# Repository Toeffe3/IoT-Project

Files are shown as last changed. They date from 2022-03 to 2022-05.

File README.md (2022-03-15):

# IoT-Project
University Project designing an IoT system

# Setup IDE
### Microchip studio

Following architectures are required:



_Run the `as-installer-*.exe` and select `AVR` and `UC3` (click **Repair**, if you have MCS installed but missing any of the architectures)_

Following extensions are optional:
* `ClangFormat`
* `Git Source Controle Provider`

---

**Integrate with Git trickery**

Open the project the first time by double-clicking the `IoT-Project.atsln` file, if no projects apperes in the Solution Explorer, you have to manually add them by left-clicking the Solution -> Add -> Existing Project -> Navigate to either one of the `*.ccproj` files, and repeat for the other.

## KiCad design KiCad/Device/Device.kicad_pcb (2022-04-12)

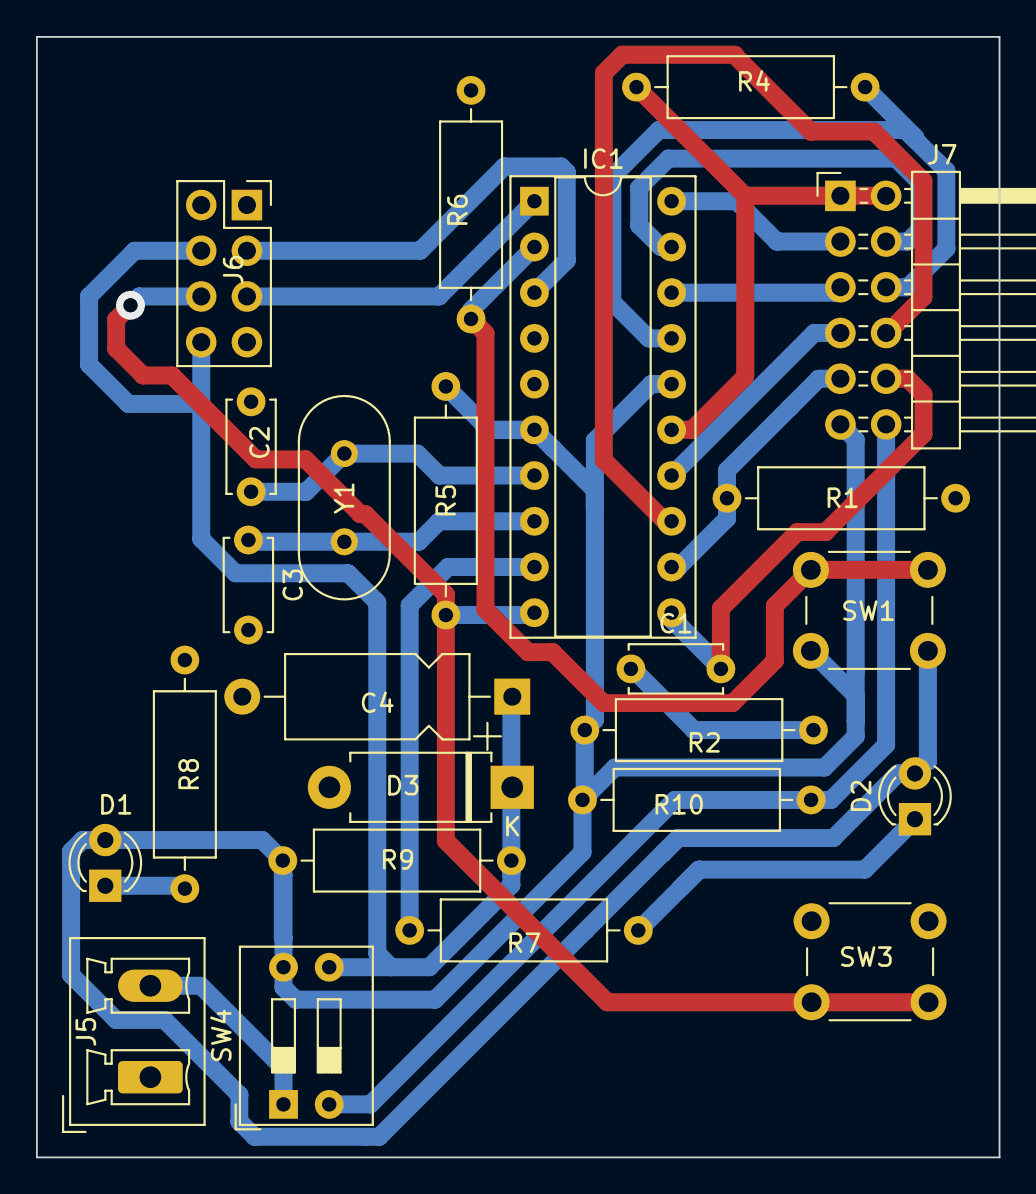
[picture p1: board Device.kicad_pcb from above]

Board: 2 copper layers, 53.5 x 62.2 mm, 24 parts (0 on the bottom side), 23 nets.

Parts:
C1: 1uF; C_Disc_D5.0mm_W2.5mm_P5.00mm
C2, C3: 20pF; C_Disc_D5.0mm_W2.5mm_P5.00mm
C4: 200n; CP_Axial_L10.0mm_D4.5mm_P15.00mm_Horizontal
D1: RødLED; LED_D3.0mm_FlatTop
D2: GrønLED; LED_D3.0mm_FlatTop
D3: BZX79C3V3; D_DO-15_P10.16mm_Horizontal
IC1: ATTINY167-XUR; DIP-20_W7.62mm_Socket
J5: VCC; PhoenixContact_MCV_1,5_2-G-5.08_1x02_P5.08mm_Vertical
J6: ESP8266(wifi); PinSocket_2x04_P2.54mm_Vertical
J7: Conn_02x06_Counter_Clockwise; PinHeader_2x06_P2.54mm_Horizontal
R1: 10k; R_Axial_DIN0309_L9.0mm_D3.2mm_P12.70mm_Horizontal
R2: 2.2k; R_Axial_DIN0309_L9.0mm_D3.2mm_P12.70mm_Horizontal
R4: 100k; R_Axial_DIN0309_L9.0mm_D3.2mm_P12.70mm_Horizontal
R5, R6: 1k; R_Axial_DIN0309_L9.0mm_D3.2mm_P12.70mm_Horizontal
R7, R8: 200; R_Axial_DIN0309_L9.0mm_D3.2mm_P12.70mm_Horizontal
R9, R10: 15; R_Axial_DIN0309_L9.0mm_D3.2mm_P12.70mm_Horizontal
SW1, SW3: SW_MEC_5E; SW_PUSH_6mm_H4.3mm
SW4: SW_DIP_x02; SW_DIP_SPSTx02_Slide_9.78x7.26mm_W7.62mm_P2.54mm
Y1: Crystal; Crystal_HC18-U_Vertical

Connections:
+3V3: C4.1, D3.1 (K), J6.4, J6.8, R9.1, SW4.3
+5V: D1.2 (A), D2.2 (A), IC1.6 (VCC), IC1.16 (AVCC), J7.11, R2.2, R5.2, R9.2, R10.1, SW1.1, SW4.4
Button01: IC1.2 (PB1/DO/OC1BU/PCINT9), R6.1, SW1.2 (A)
DHT11: IC1.20 (PA0/RXLIN/RXD/ADC0/PCINT0), J7.3
GND: C2.2, C3.2, C4.2, D3.2 (A), IC1.5 (GND), IC1.15 (AGND), J5.1, J6.1, J7.1, J7.2, R1.2, R4.2, R6.2, R8.2, SW3.1
LED_G: IC1.9 (PB6/INT0/OC1AX/ADC9/PCINT14), R7.2
MIC: C1.1, R2.1
unnamed: D1.1 (K), R8.1
unnamed: D2.1 (K), R7.1
unnamed: J5.2, SW4.1
OPTISK: IC1.17 (PA3/INT1/ISRC/ADC3/PCINT3), J7.6, R4.1
PHOTRAN: IC1.12 (PA6/~SS/AIN0/ADC6/PCINT6), J7.9, R1.1
Reset: IC1.10 (PB7/DW/~RESET/OC1BX/ADC10/PCINT15), J6.6, R5.1, SW3.2 (A)
SCL: IC1.3 (PB2/SCL/USCK/OC1AV/PCINT10), J6.3
SDA: IC1.1 (PB0/SDA/DI/OCR1AU/PCINT8), J6.5
UP1: IC1.19 (PA1/TXLIN/TXD/ADC1/PCINT1), J7.4
UP2: IC1.18 (PA2/MISO/DO/OC0A/ADC2/PCINT2), J7.5
UP4: IC1.14 (PA4/MOSI/SDA/DI/ICP1/ADC4/PCINT4), J7.7
UP5: IC1.13 (PA5/SCK/SCL/USCK/T1/ADC5/PCINT5), J7.8
UP7: C1.2, IC1.11 (PA7/AREF/XREF/AIN1ADC7/PCINT7), J7.10
UPWR: J7.12, R10.2, SW4.2
XTAL1: C2.1, IC1.7 (PB4/CLKI/XTAL1/OC1AW/PCINT12), Y1.1
XTAL2: C3.1, IC1.8 (PB5/CLKO/XTAL2/OC1BW/ADC8/PCINT13), Y1.2

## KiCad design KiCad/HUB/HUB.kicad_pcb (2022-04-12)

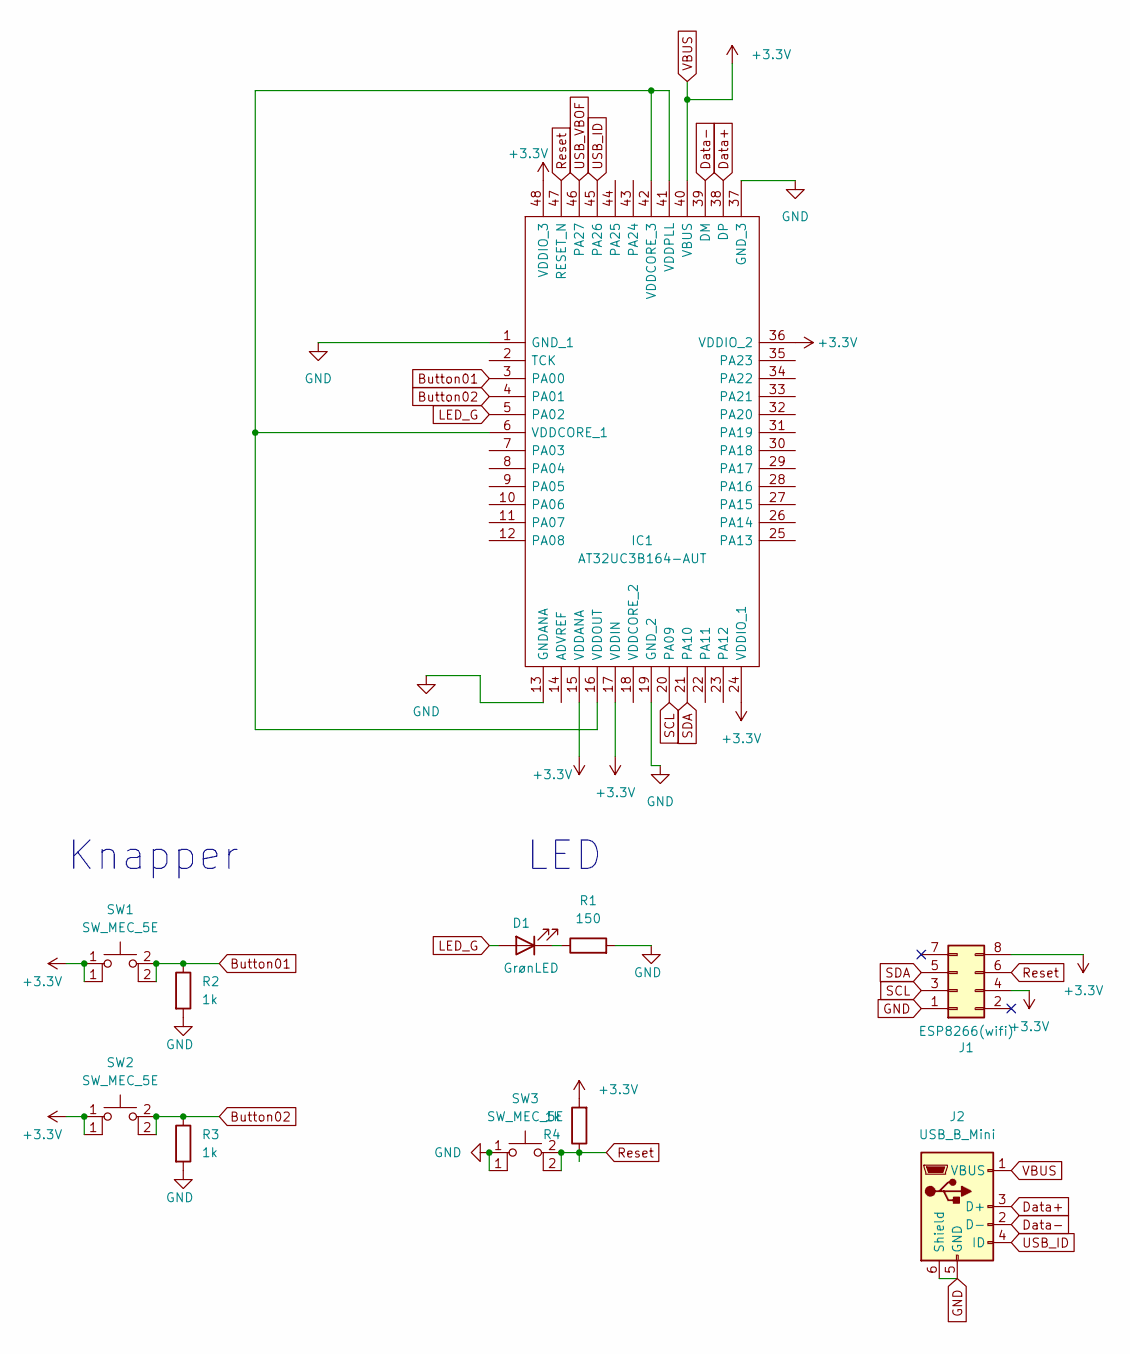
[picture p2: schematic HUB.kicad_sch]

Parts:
D1: GrønLED; LED_D3.0mm_FlatTop
IC1: AT32UC3B164-AUT; QFP50P900X900X120-48N; Mouser Part Number 556-AT32UC3B164-AUT
J1: ESP8266(wifi); PinSocket_2x04_P2.54mm_Vertical
J2: USB_B_Mini; USB_Mini-B_Lumberg_2486_01_Horizontal
R1: 150; R_Axial_DIN0309_L9.0mm_D3.2mm_P12.70mm_Horizontal
R2, R3, R4: 1k; R_Axial_DIN0309_L9.0mm_D3.2mm_P12.70mm_Horizontal
SW1, SW2, SW3: SW_MEC_5E; SW_PUSH_6mm_H4.3mm

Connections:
Button01: IC1.3 (PA00), R2.1, SW1.2 (A)
Button02: IC1.4 (PA01), R3.1, SW2.2 (A)
Data+: IC1.38 (DP), J2.3 (D+)
Data-: IC1.39 (DM), J2.2 (D-)
GND: IC1.1 (GND_1), IC1.13 (GNDANA), IC1.19 (GND_2), IC1.37 (GND_3), J1.1, J2.5 (GND), J2.6 (Shield), R1.2, R2.2, R3.2, SW3.1
LED_G: D1.2 (A), IC1.5 (PA02)
unnamed: D1.1 (K), R1.1
unnamed: IC1.6 (VDDCORE_1), IC1.16 (VDDOUT), IC1.41 (VDDPLL), IC1.42 (VDDCORE_3)
Reset: IC1.47 (RESET_N), J1.6, R4.1, SW3.2 (A)
SCL: IC1.20 (PA09), J1.3
SDA: IC1.21 (PA10), J1.5
USB_ID: IC1.45 (PA26), J2.4 (ID)
USB_VBOF: IC1.46 (PA27)
VBUS: IC1.15 (VDDANA), IC1.17 (VDDIN), IC1.24 (VDDIO_1), IC1.36 (VDDIO_2), IC1.40 (VBUS), IC1.48 (VDDIO_3), J1.4, J1.8, J2.1 (VBUS), R4.2, SW1.1, SW2.1

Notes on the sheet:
LED
Knapper

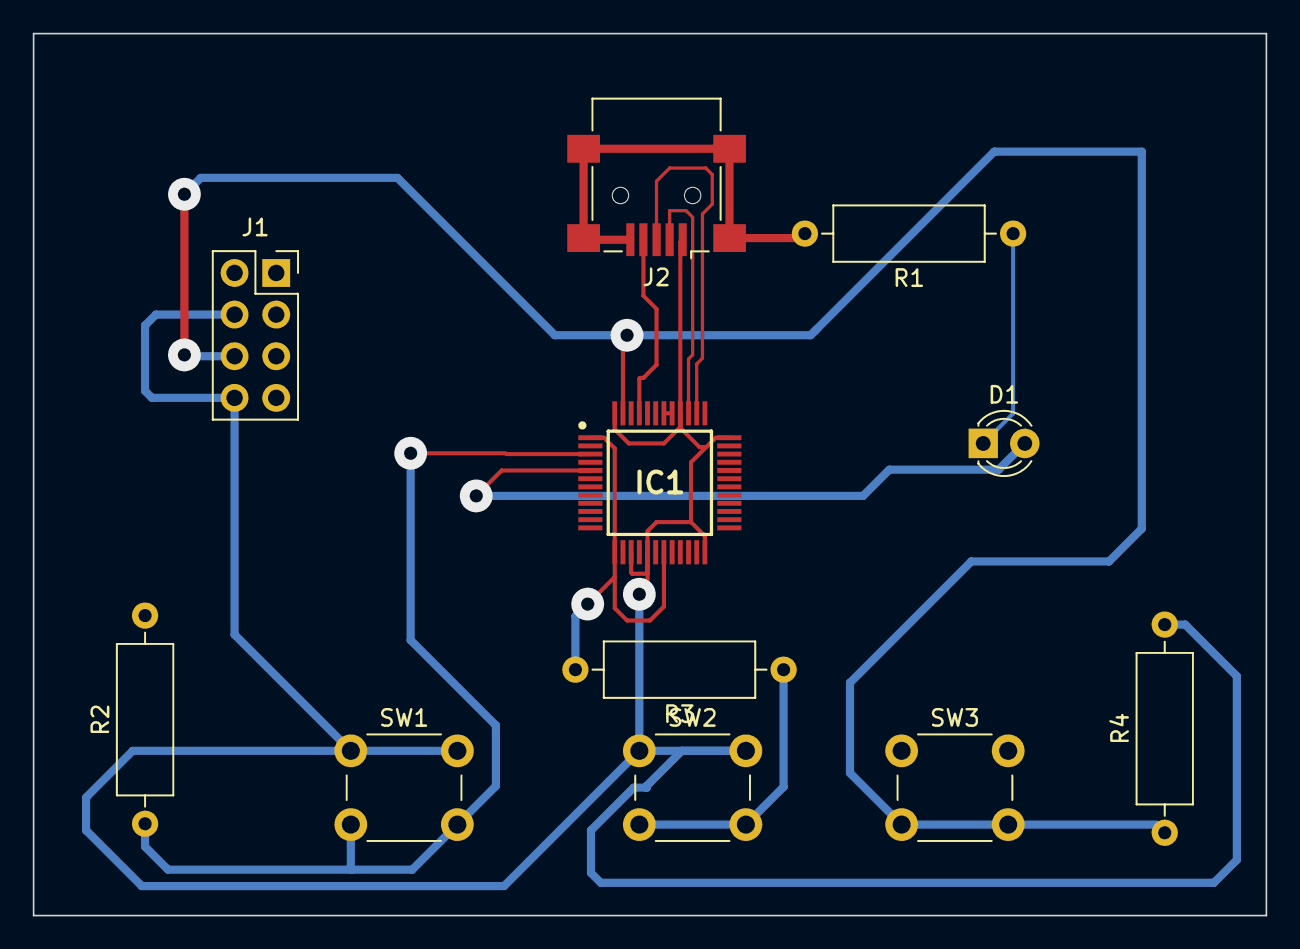
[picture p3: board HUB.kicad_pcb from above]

Board: 2 copper layers, 75.2 x 53.8 mm, 11 parts (0 on the bottom side), 13 nets.

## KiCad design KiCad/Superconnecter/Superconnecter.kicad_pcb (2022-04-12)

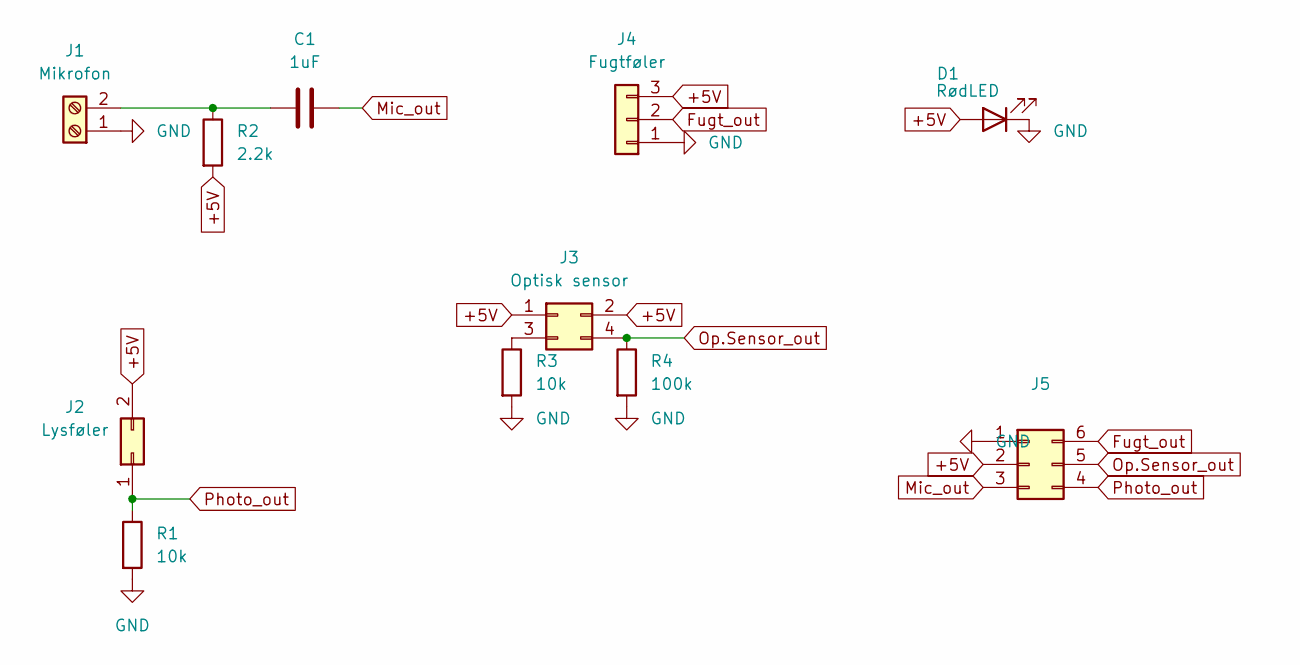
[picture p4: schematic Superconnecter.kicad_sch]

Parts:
C1: 1uF; C_Disc_D5.0mm_W2.5mm_P5.00mm
D1: RødLED; LED_D3.0mm_FlatTop
J1: Mikrofon; PhoenixContact_MCV_1,5_2-G-5.08_1x02_P5.08mm_Vertical
J2: Lysføler; PinSocket_2x01_P2.54mm_Vertical
J3: Optisk sensor; PinSocket_2x02_P2.54mm_Vertical
J4: Fugtføler; PinSocket_1x03_P2.54mm_Vertical
J5: (no value)
R1, R3: 10k; R_Axial_DIN0309_L9.0mm_D3.2mm_P12.70mm_Horizontal
R2: 2.2k; R_Axial_DIN0309_L9.0mm_D3.2mm_P12.70mm_Horizontal
R4: 100k; R_Axial_DIN0309_L9.0mm_D3.2mm_P12.70mm_Horizontal

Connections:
+5V: D1.2 (A), J2.2, J3.1, J3.2, J4.3, J5.2, R2.2
Fugt_out: J4.2, J5.6
GND: D1.1 (K), J1.1, J4.1, J5.1, R1.2, R3.2, R4.2
Mic_out: C1.2, J5.3
unnamed: C1.1, J1.2, R2.1
unnamed: J3.3, R3.1
Op.Sensor_out: J3.4, J5.5, R4.1
Photo_out: J2.1, J5.4, R1.1

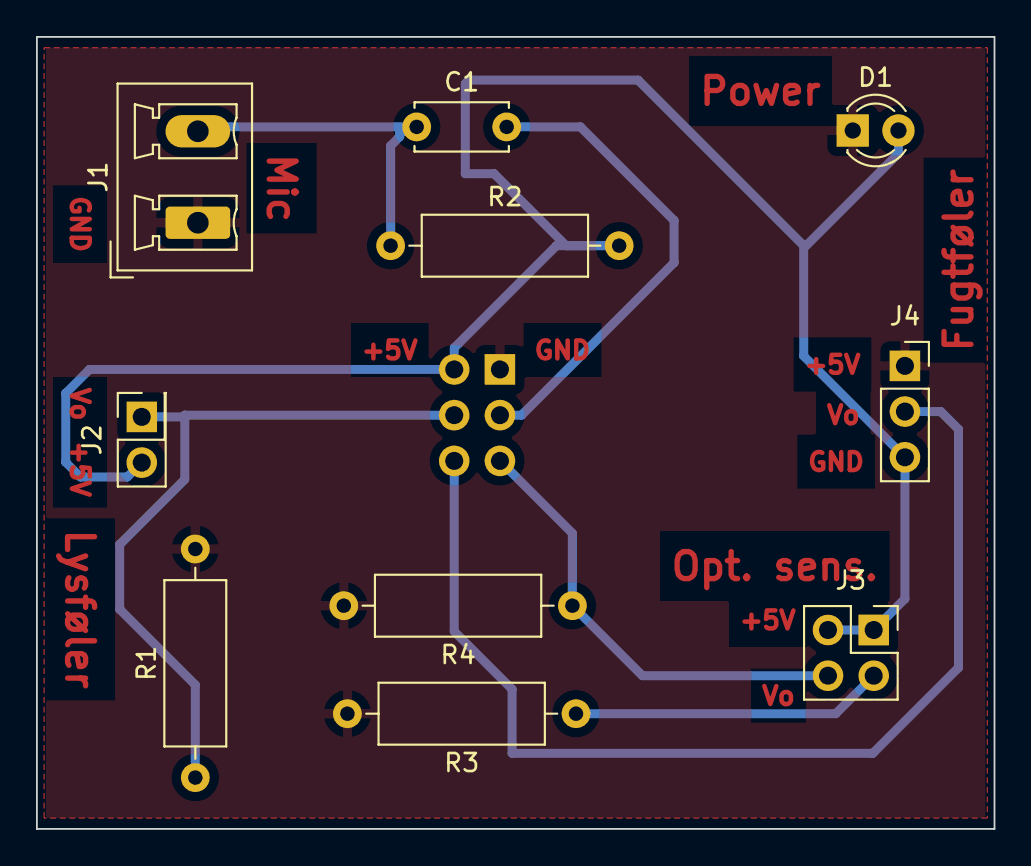
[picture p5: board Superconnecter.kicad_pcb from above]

Board: 2 copper layers, 53.2 x 44.0 mm, 11 parts (1 on the bottom side), 8 nets.

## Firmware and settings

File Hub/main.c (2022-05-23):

/******************************************************************************/
/* Project:    Hub                                                            */
/* File:       main.c                                                         */
/* Decription: Hub main file                                                  */
/******************************************************************************/

/***************************** Include files *******************************/
#include <stdint.h>
//
#include "FreeRTOS.h"
#include "tm4c123gh6pm.h"
//
#include "stream_buffer.h"
#include "systick_frt.h"
#include "task.h"
//
#include "com.h"
#include "lcd.h"
#include "status_led.h"
#include "uart0.h"

/*****************************    Defines    *******************************/
#define USERTASK_STACK_SIZE configMINIMAL_STACK_SIZE

/*****************************   Variables   *******************************/
//@formatter:off
char sensor_text[5][16] = {{"Unknown sensor  "},
						   {"Light value:    "},
						   {"IR detector:    "},
						   {"Color intensity:"},
						   {"Sound level:    "}};
//@formatter:on

bool init_mode = false;

/*****************************   Functions   *******************************/
void controller_task (void* pvParameters) {

  size_t   i = 0;
  char	   data[32];
  char	   str[32];
  uint16_t timeout;

  lcd_write_buffer (SCREEN_CLEAR);
  vTaskDelay (500 / portTICK_RATE_MS);

  uart0_println ("Press 'I' for setup");
  lcd_write_buffer ("Please setup                    ");

  vTaskDelay (1000 / portTICK_RATE_MS);

  while (1) {
	if (uart0_rx_ready ( ) && uart0_get_char ( ) == 'I') {
	  uart0_println ("Please type sensor CODE (3 uppercase letters):");
	  char tmp[3] = {'\0'};

	  while (!uart0_rx_ready ( ))
		;
	  tmp[0] = uart0_get_char ( );

	  while (!uart0_rx_ready ( ))
		;
	  tmp[1] = uart0_get_char ( );

	  while (!uart0_rx_ready ( ))
		;
	  tmp[2] = uart0_get_char ( );

	  uart0_print ("Send command: ");
	  uart0_println (tmp);
	  com_write_buffer (tmp);

	  /* */ if (strncmp (tmp, "LDR", 3) == 0)
		device_type = SENSOR_LDR;
	  else if (strncmp (tmp, "IRD", 3) == 0)
		device_type = SENSOR_IRD;
	  else if (strncmp (tmp, "CNY", 3) == 0)
		device_type = SENSOR_CNY;
	  else if (strncmp (tmp, "MIC", 3) == 0)
		device_type = SENSOR_MIC;

	  init_mode = true;

	  vTaskDelay (1000 / portTICK_RATE_MS);

	} else if (xStreamBufferReceive (com_in, &data, 1, COM_SPEED * 2) == pdPASS) {
	  str[i++] = *data;
	} else if (i > 0) {

	  if (init_mode) {
		uart0_print ("Got command: ");
		uart0_println (str);
		if (!(strncmp (str, "OK!", 3) == 0))
		  device_type = SENSOR_UNKNOWN;
		else
		  init_mode = false;
		timeout = 10;
	  } else if (device_type != SENSOR_UNKNOWN) {
		uart0_print ("Got data: ");
		uart0_println (str);
		lcd_write_buffer (SCREEN_CLEAR);
		lcd_write_buffer_size (sensor_text[device_type], 16);
		lcd_write_buffer (str);
	  }

	  timeout = 5;
	  while (i > 0)
		str[i--] = '\0';

	} else if (device_type != SENSOR_UNKNOWN && timeout == 0) {
	  xStreamBufferReset (com_out);
	  uart0_println ("Send command: REQ");
	  com_write_buffer ("REQ");
	  timeout = 3;
	}
	vTaskDelay (1000 / portTICK_RATE_MS);
	timeout--;
  }
}

static void setupHardware (void) {
  uart_init ( );
  init_systick ( );
}

int main (void) {
  static uint8_t priority = 10;
  setupHardware ( );
  xTaskCreate (com_task, "COM", USERTASK_STACK_SIZE, NULL, --priority, NULL);
  xTaskCreate (status_led_task, "LED", USERTASK_STACK_SIZE, NULL, --priority, NULL);
  xTaskCreate (controller_task, "CONT", USERTASK_STACK_SIZE, NULL, --priority, NULL);
  xTaskCreate (lcd_task, "LCD", USERTASK_STACK_SIZE, NULL, --priority, NULL);
  vTaskStartScheduler ( );
  return 0;
}

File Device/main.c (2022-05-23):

/******************************************************************************/
/* Project:    Device                                                         */
/* File:       main.c                                                         */
/* Decription: Device main file                                               */
/******************************************************************************/

/***************************** Include files *******************************/
#include "src/header.h"

/*****************************    Defines    *******************************/
// Select which if any modules should be reduced to save power
#define USING_DELAY // Use delay ms requires timer 1
#define USING_ADC

#define MODE_LDR 1
#define MODE_IRD 2
#define MODE_CNY 3
#define MODE_MIC 4

/*****************************   Functions   *******************************/
int main (void) {

  // Setup
  uint8_t mode				 = 0;
  uint8_t power_down_modules = PWR_USI | PWR_LIN | PWR_TI0;

#ifndef USING_DELAY
  power_down_modules |= PWR_TI1;
#endif

  power_init (			   // Minimize power usage
	  POWER_HIGH,		   // Decides which clocks keeps running
	  false,			   // Do not Disable Brown out detection
	  power_down_modules); // Modules that should be turned off

  LED_init ( );
  com_init ( );

  _delay_ms (COM_SPEED * 10);

  // Loop
  while (1) {

	char str[4] = {'\0'};
	com_wait_for_signal ( );
	com_get_string (str);

	_delay_ms (COM_SPEED * 10);

	if (strncmp (str, "REQ", 2) == 0) {

	  LED_on ( );
	  _delay_ms (COM_SPEED * 10);

	  switch (mode) {
		case MODE_LDR:
		  com_send_num (LDR_read ( ));
		  break;

		case MODE_IRD:
		  if (IRD_read ( ))
			com_send_string ("1");
		  else
			com_send_string ("0");
		  break;

		case MODE_CNY:
		  com_send_num (CNY_read ( ));
		  break;

		case MODE_MIC:
		  com_send_num (MIC_read ( ));
		  break;

		default:
		  com_send_string ("UD!"); // Unknown device
	  }							   // END SWITCH MODE
	  LED_off ( );
	} else if (strncmp (str, "LDR", 2) == 0) {
	  LDR_init ( );
	  mode = MODE_LDR;
	  com_send_string ("OK!");
	} else if (strncmp (str, "IRD", 2) == 0) {

	  IRD_init ( );
	  mode = MODE_IRD;
	  com_send_string ("OK!");
	} else if (strncmp (str, "CNY", 2) == 0) {

	  CNY_init ( );
	  mode = MODE_CNY;
	  com_send_string ("OK!");
	} else if (strncmp (str, "MIC", 2) == 0) {
	  MIC_init ( );
	  mode = MODE_MIC;
	  com_send_string ("OK!");
	} else {
	  com_send_string (str); // Unknown command
	}

	_delay_ms (COM_SPEED * 10);
  }
}

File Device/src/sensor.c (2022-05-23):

/******************************************************************************/
/* Project:    Device                                                         */
/* File:       src/sensor.c                                                   */
/* Decription: Device sensor control                                          */
/******************************************************************************/

/***************************** Include files *******************************/
#include "sensor.h"

/*****************************   Variables   *******************************/
bool btn;

/*****************************   Functions   *******************************/
void IRD_init (void) {
  // Configure IR movement detector as input
  DDR_IRD = (0 << PIN_IRD);
}

bool IRD_read (void) { return (IRD & (1 << PIN_IRD)) != 0; }

void LDR_init (void) {
  // Configure LDR as input
  DDR_LDR = (0 << PIN_LDR);
  ADMUX   = (1 << REFS1) | (1 << REFS0) // Use 2.56V AREF
		  | (0 << ADLAR) | 0b00110;		// Right adjust, PA6
  ADCSRA = (1 << ADEN) | (0 << ADSC) |  // Enable, Pause
		   (0 << ADATE) | (0 << ADIF) | // No auto
		   (0 << ADIE) | (0 << ADPS2) | // No interupt
		   (0 << ADPS1) | (1 << ADPS0); // Prescale 2
}

uint16_t LDR_read (void) {
  ADCSRA |= (1 << ADSC); // Start ADC
  while (ADCSRA & (1 << ADSC))
	; // Wait for conversion
  return ADC;
}

uint16_t HUM_wait_for_high (void) {
  uint16_t timeout = DHT_TIMEOUT;
  while (PORT_HUM & (1 << PIN_HUM) != 0)
	if (!timeout--)
	  break;
  return timeout;
}

uint16_t HUM_wait_for_low (void) {
  uint16_t timeout = DHT_TIMEOUT;
  while (PORT_HUM & (1 << PIN_HUM) == 0)
	if (!timeout--)
	  break;
  return timeout;
}

bool DHT_get_one_bit (void) {
  if (!HUM_wait_for_low ( ))
	return false;
  uint8_t timediff = HUM_wait_for_high ( );
  if (timediff == 0)
	return 0;
  return (timediff >= 40 * F_CPU / 1000000); // ~40us
}

void HUM_init (void) {
  DDR_HUM  = (1 << PIN_HUM);  // OUTPUT
  PORT_HUM = ~(1 << PIN_HUM); // LOW
}

uint8_t HUM_get (uint16_t *temperature, uint16_t *humidity) {
  uint16_t timeout  = 0;
  uint8_t  checksum = 0;
  uint8_t  res;

  uint8_t buffer[5]; // 8*5 = 40

  // Start transaction
  DDR_HUM |= (1 << PIN_HUM);   // OUTPUT
  PORT_HUM &= ~(1 << PIN_HUM); // LOW
  _delay_ms (18);			   // 18ms
  DDR_HUM &= ~(1 << PIN_HUM);  // INPUT

  HUM_wait_for_low ( );
  HUM_wait_for_high ( );

  // Get bits
  for (uint8_t i = 0; i < 5; i++) {
	uint8_t temp = 0;

	for (uint8_t j = 8; j > 0; j--)
	  temp = DHT_get_one_bit ( ) << j;

	buffer[i] = temp;
  }

  *humidity	= (buffer[0] << 8) + buffer[1];
  *temperature = (buffer[2] << 8) + buffer[3];

  if ((uint8_t)*humidity + (uint8_t)*temperature == buffer[4])
	return 0;
  else
	return 3;
}

void MIC_init (void) {
  // Configure MIC as input
  DDR_LDR = (0 << PIN_MIC);
  ADMUX   = (1 << REFS1) | (1 << REFS0) // Use 2.56V AREF
		  | (0 << ADLAR) | 0b00110;		// Right adjust, PA6
  ADCSRA = (1 << ADEN) | (0 << ADSC) |  // Enable, Pause
		   (0 << ADATE) | (0 << ADIF) | // No auto
		   (0 << ADIE) | (0 << ADPS2) | // No interupt
		   (1 << ADPS1) | (0 << ADPS0); // Prescale 4
}

uint16_t MIC_read (void) {
  ADCSRA |= (1 << ADSC); // Start ADC
  while (ADCSRA & (1 << ADSC))
	; // Wait for conversion
  return ADC;
}

void CNY_init (void) {
  // Configure optic sensor as input
  DDR_CNY = ~(1 << PIN_CNY);
  ADMUX   = (1 << REFS1) | (1 << REFS0) // Use 2.56V AREF
		  | (0 << ADLAR) | 0b00011;		// Right adjust, PA3
  ADCSRA = (1 << ADEN) | (0 << ADSC) |  // Enable, Pause
		   (0 << ADATE) | (0 << ADIF) | // No auto
		   (0 << ADIE) | (0 << ADPS2) | // No interupt
		   (1 << ADPS1) | (0 << ADPS0); // Prescale 4
}

uint16_t CNY_read (void) {
  ADCSRA |= (1 << ADSC); // Start ADC
  while (ADCSRA & (1 << ADSC))
	; // Wait for conversion
  return ADC;
}

void BUT_init ( ) {
  DDR_BUT = (0 << PIN_BUT);
  PCICR   = (1 << PCIE1);
  PCMSK1  = (1 << PCINT9);
}

void TEMP_init (void) {
  ADMUX = (0 << REFS1) | (1 << REFS0)   // Use 1.1V AREF
		  | (0 << ADLAR) | 0b01011;		// Right adjust, Temperature sensor
  ADCSRA = (1 << ADEN) | (0 << ADSC) |  // Enable, Pause
		   (0 << ADATE) | (0 << ADIF) | // No auto
		   (0 << ADIE) | (0 << ADPS2) | // No interupt
		   (1 << ADPS1) | (0 << ADPS0); // Prescale 4
}

float TEMP_read (void) {
  ADCSRA |= (1 << ADSC);		   // Start ADC
  float k = 1.05, offset = -272.9; // Constants
  while (ADCSRA & (1 << ADSC))
	;						 // Wait for conversion
  return (k * ADC) + offset; // calculate
}

ISR (PCINT1_vect) { btn = (BUT & (1 << PIN_BUT)) != 0; }

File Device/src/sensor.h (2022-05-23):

/******************************************************************************/
/* Project:    Device                                                         */
/* File:       src/sensor.h                                                   */
/* Decription: Device sensor control header                                   */
/******************************************************************************/

#ifndef SENSOR_H_
#define SENSOR_H_

/***************************** Include files *******************************/
#include "header.h"

/*****************************    Defines    *******************************/
#define DHT_TIMEOUT 1000

// Infrared movement detector
#define PORT_IRD PORTA
#define DDR_IRD DDRA
#define PIN_IRD PINA2
#define IRD PINA

// Light dependent resistor
#define PORT_LDR PORTA
#define DDR_LDR DDRA
#define PIN_LDR PINA6
#define LDR PINA

// Humidity sensor
#define PORT_HUM PORTA
#define DDR_HUM DDRA
#define PIN_HUM PINA0
#define HUM PINA

// Microphone
#define PORT_MIC PORTA
#define DDR_MIC DDRA
#define PIN_MIC PINA6
#define MIC PINA

// CNY70 Optical sensor
#define PORT_CNY PORTA
#define DDR_CNY DDRA
#define PIN_CNY PINA3
#define CNY PINA

// Button D1
#define PORT_BUT PORTB
#define DDR_BUT DDRB
#define PIN_BUT PINB1
#define BUT PINB

/*****************************   Variables   *******************************/
extern bool btn;

/*****************************   Functions   *******************************/
void	 IRD_init (void);
bool	 IRD_read (void);
void	 LDR_init (void);
uint16_t LDR_read (void);
uint16_t HUM_wait_for_high (void);
uint16_t HUM_wait_for_low (void);
bool	 DHT_get_one_bit (void);
void	 HUM_init (void);
uint8_t  HUM_get (uint16_t *temperature, uint16_t *humidity);
void	 MIC_init (void);
uint16_t MIC_read (void);
void	 CNY_init (void);
uint16_t CNY_read (void);
void	 BUT_init ( );
void	 TEMP_init (void);
float	TEMP_read (void);
#endif /* SENSOR_H_ */

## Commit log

2022-03-10 🎨 Formattede code
2022-03-29 Added Projectplan.xlsx
    [Projektplan.xlsx]
2022-03-30 Init kicad
    [Device.kicad_pcb, Device.kicad_sch, HUB.kicad_pcb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]
2022-03-30 Tilføjelse til Device
    [Device.kicad_sch]
2022-03-30 device tilføjelse
    [Device.kicad_sch]
2022-03-30 Device tilføjelser
    [Device.kicad_sch]
2022-03-30 I2C pretest
2022-04-04 kicad device fodlister
    [Device.kicad_pcb, Device.kicad_sch]
2022-04-05 spreadout board to device
    [Device_Spreadout.kicad_pcb, Device_Spreadout.kicad_sch]
2022-04-05 Opdatering af device kicad
    [Device.kicad_sch]
2022-04-05 Minor fixes
    [Device.kicad_sch]
2022-04-05 fix ic
    [Device.kicad_sch]
2022-04-05 Opdatering af switches
    [Device.kicad_pcb, Device.kicad_sch]
2022-04-06 flip sides
    [Device.kicad_pcb]
2022-04-06 Change track width
    [Device_Spreadout.kicad_sch]
2022-04-07 AVRDUDE configuration for device
2022-04-07 Fix device
2022-04-07 Næsten_færdigt_pcb
    [HUB.kicad_pcb, HUB.kicad_sch]
2022-04-20 Device (post test)
2022-05-14 power pretest
2022-05-18 temperatur (doesn't work)
2022-05-23 fix FRT10 folder
    Needed to remove comit and add again, mv did not detect it
    [startup_frt.c]
